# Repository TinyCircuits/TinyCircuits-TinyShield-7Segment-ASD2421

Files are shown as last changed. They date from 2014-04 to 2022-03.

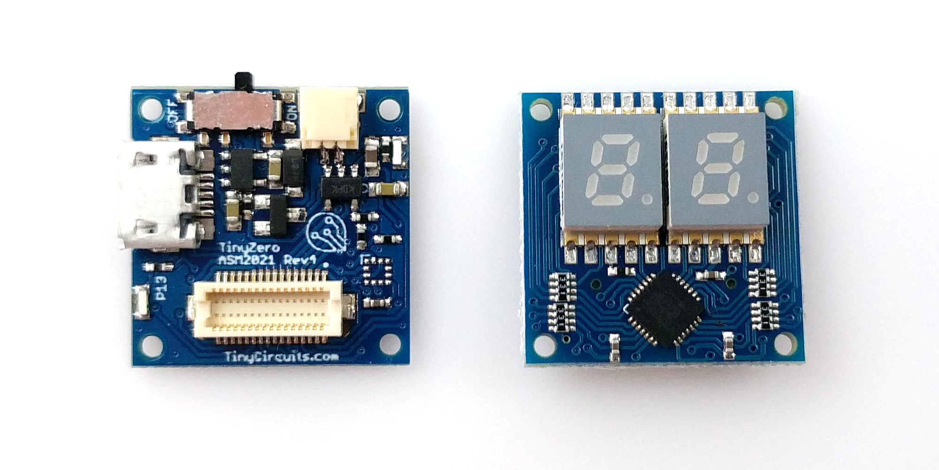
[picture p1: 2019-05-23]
images/ASD2421-R-N-Tutorial-Image-02.jpg

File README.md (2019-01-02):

# TinyCircuits TinyShield 7 Segment Display
# ASD2421 Rev2

The design files are located under design_files/ for the TinyCircuits ASD2421 Rev 2 PCB.  This is a Tiny shield board (Square Version, 20mm x 20mm) that has two seven segment displays (Red LEDs).  

Format is in Cadsoft Eagle format - Eagle version 6.2 was used for the original design.

For more infomation on this, check out the product page at TinyCircuits.com:  https://tinycircuits.com/collections/leds-displays/products/7-segment-display-tinyshield

# License:

Design by TinyCircuits.
All design files are released under the Creative Commons Attribution Share-Alike 3.0 License, see the following link for details: http://creativecommons.org/licenses/by-sa/3.0

All text above must be included in any redistribution or derived design

This project uses designs and concepts developed as part of the Arduino project and the LilyPad project.  The TinyCircuits design files themselves (schematics, PCB and libraries) are not directly derived from these works' design files and have been created new, however the concepts and basic architecture behind the TinyDuino and TinyLily products are derived and we thank the hard work of the organizations below for their contributions to open-source hardware:
  
Original Arduino Uno Design by Team Arduino

LilyPad Arduino Design by Leah Buechley and Sparkfun Electronics

Please support the open-source hardware community

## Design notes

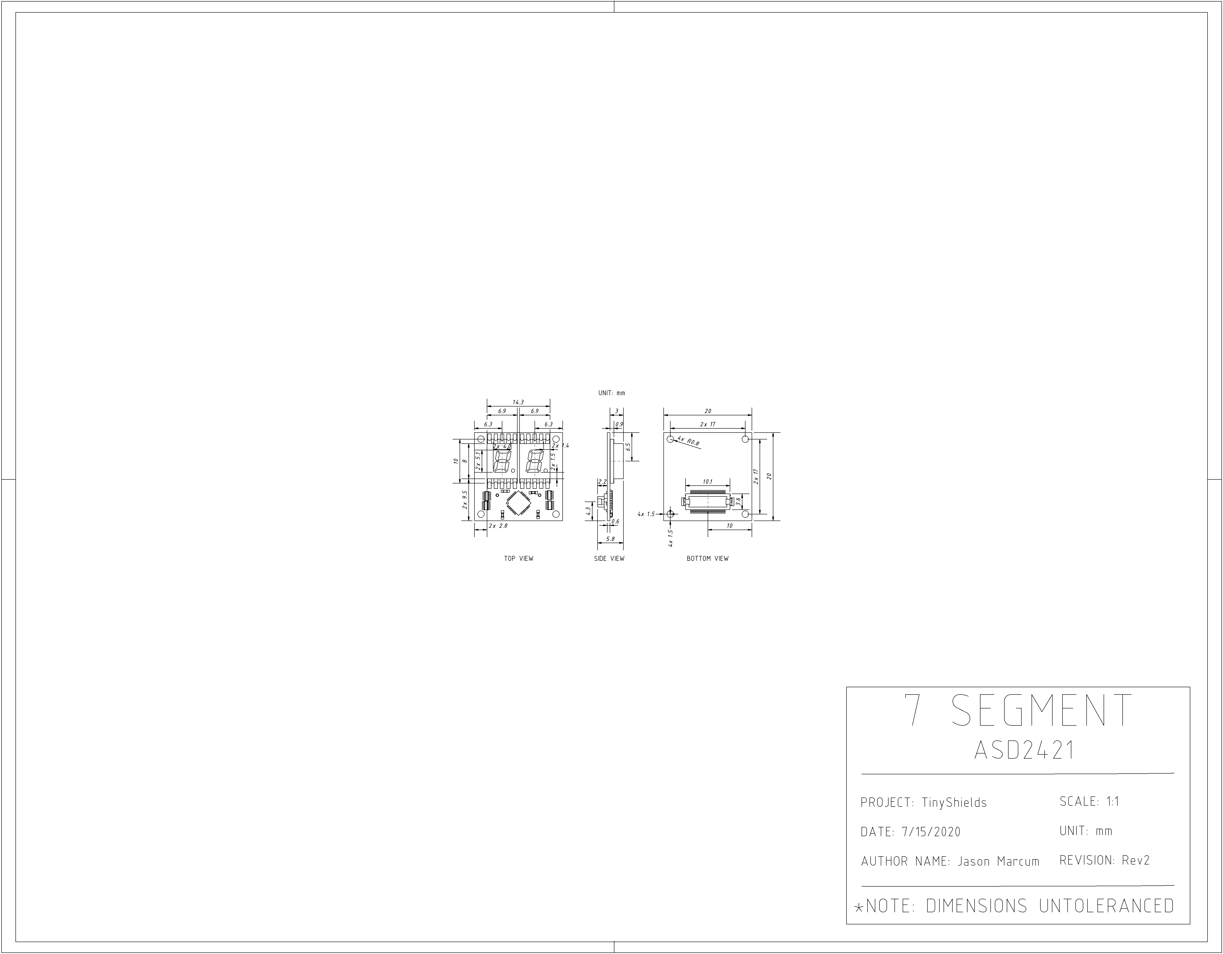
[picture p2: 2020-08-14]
cad/TinyShield_7SEGMENT_ASD2421_REV2-DETAILED_DRAWING-PNG.png

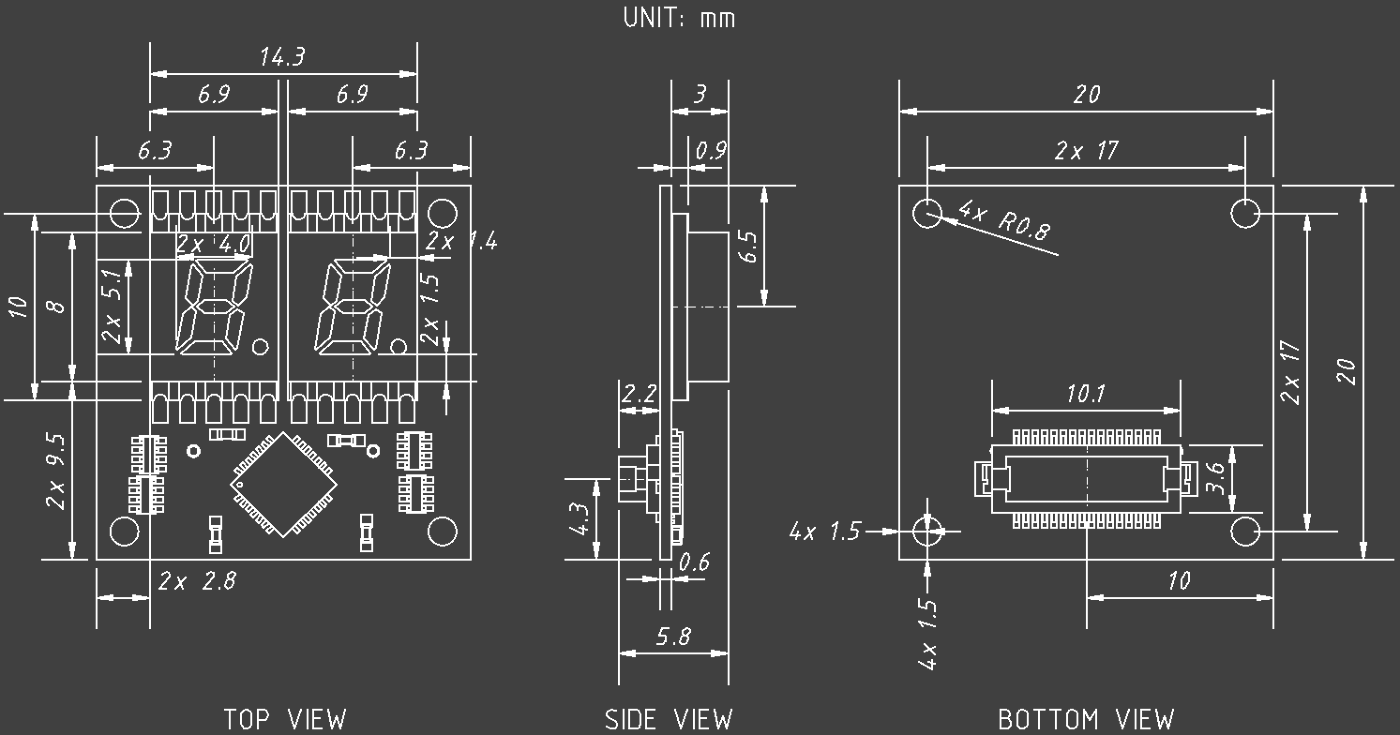
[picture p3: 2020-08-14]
cad/TinyShield_7SEGMENT_ASD2421_REV2-DETAILED_DRAWING_COMPACT-PNG.png

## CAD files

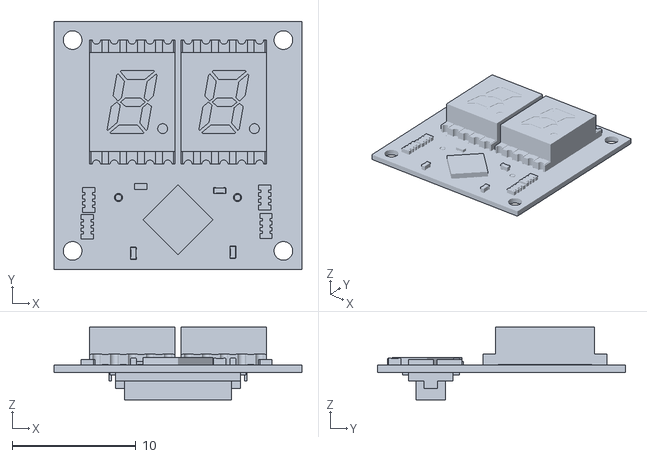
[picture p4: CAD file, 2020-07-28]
cad/TinyShield_7SEGMENT_ASD2421_REV2-STL.stl
20.0 x 20.0 x 5.85

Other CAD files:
cad/TinyShield_7SEGMENT_ASD2421_REV2-DETAILED_DRAWING-DXF.dxf

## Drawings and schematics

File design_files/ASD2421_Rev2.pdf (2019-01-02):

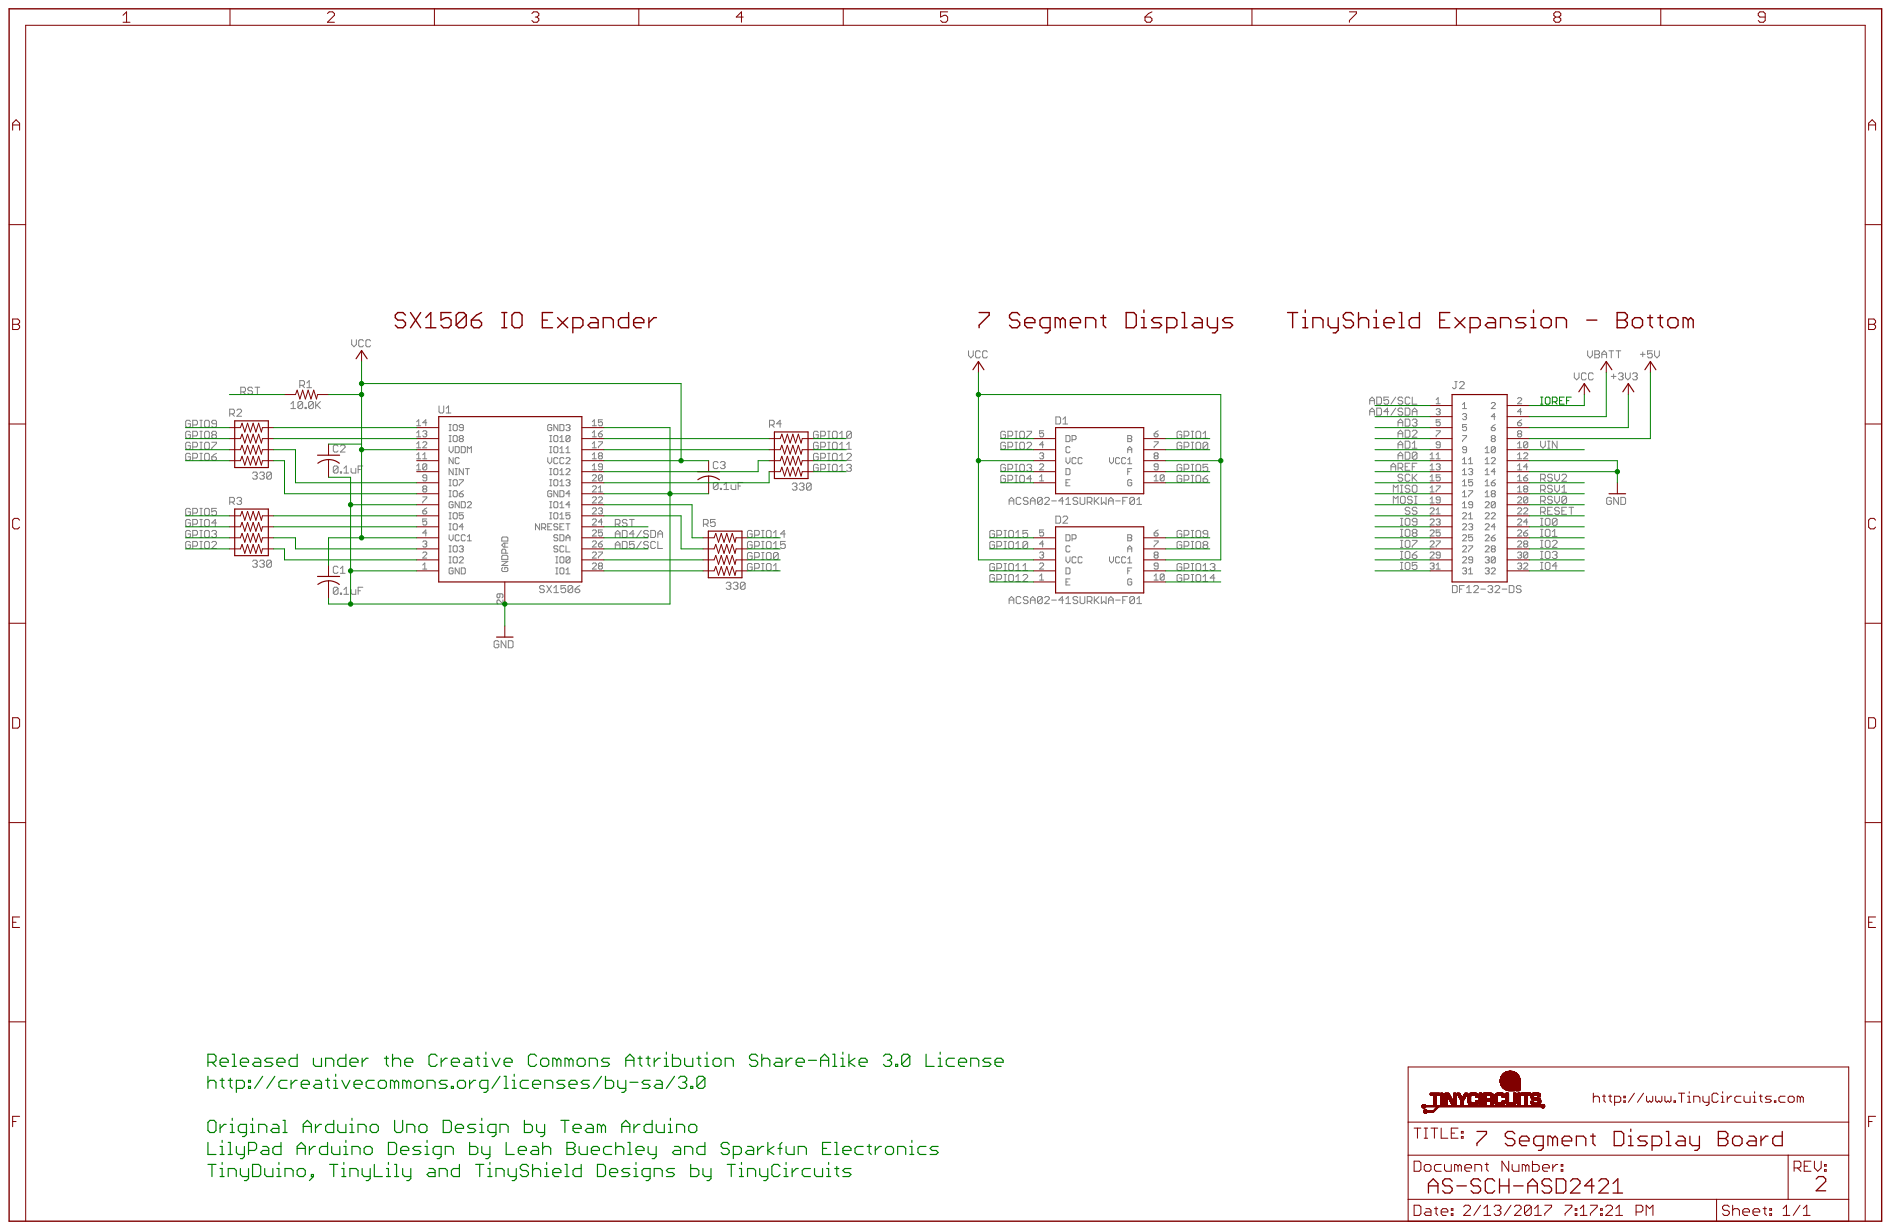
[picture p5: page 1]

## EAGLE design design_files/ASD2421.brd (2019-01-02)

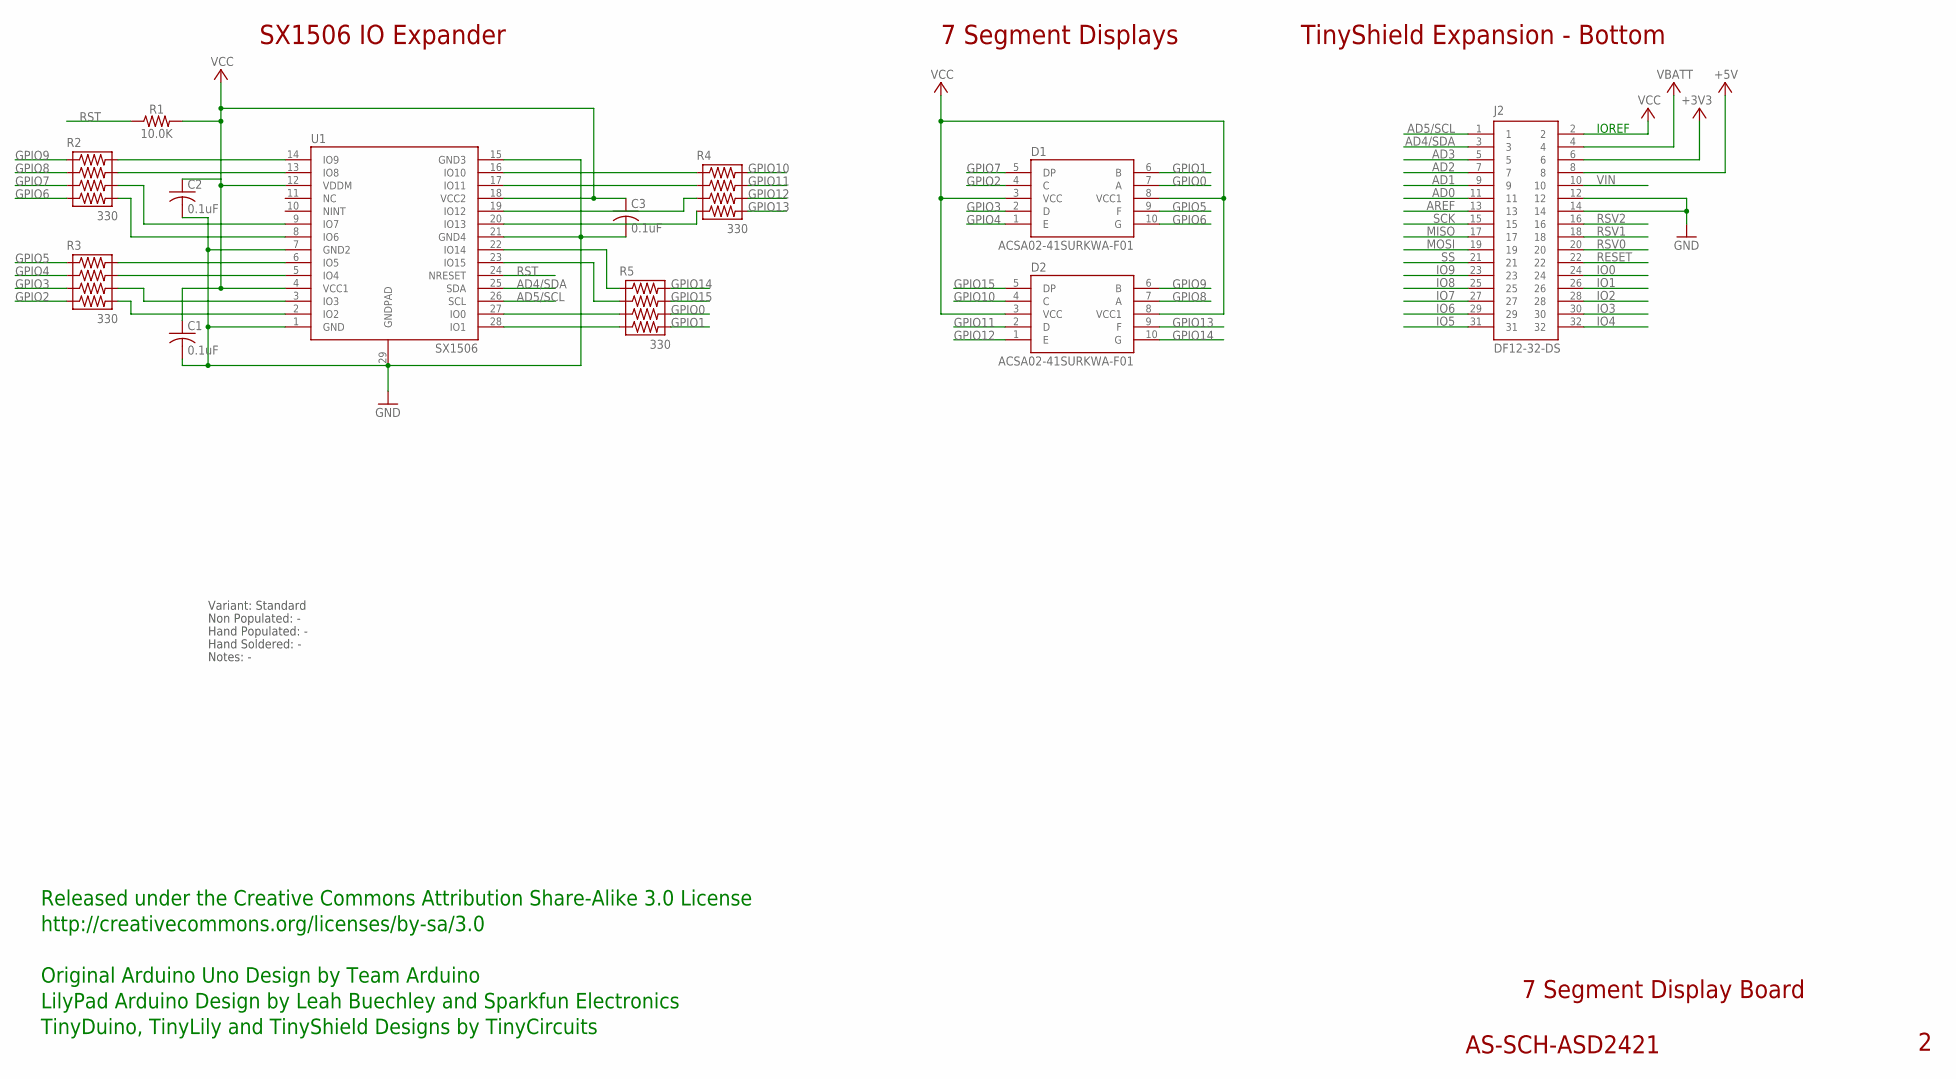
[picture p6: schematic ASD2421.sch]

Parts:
C1, C2, C3: 0.1uF; C0402
D1, D2: ACSA02-41SURKWA-F01; PARTNO AS-ITM-00133
J2: DF12-32-DS; PARTNO AS-ITM-00012
R1: 10.0K; 0402
R2, R3, R4, R5: 330; 0402RPACK
U1: SX1506; PARTNO AS-ITM-00134

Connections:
+3V3: J2.6
+5V: J2.8
AD0: J2.11
AD1: J2.9
AD2: J2.7
AD3: J2.5
AD4/SDA: J2.3, U1.25 (SDA)
AD5/SCL: J2.1, U1.26 (SCL)
AREF: J2.13
GND: C1.2, C2.2, C3.2, J2.12, J2.14, U1.1 (GND), U1.7 (GND2), U1.15 (GND3), U1.21 (GND4), U1.29 (GNDPAD)
GPIO0: D1.7 (A), R5.6
GPIO1: D1.6 (B), R5.8
GPIO2: D1.4 (C), R3.7
GPIO3: D1.2 (D), R3.5
GPIO4: D1.1 (E), R3.3
GPIO5: D1.9 (F), R3.1
GPIO6: D1.10 (G), R2.7
GPIO7: D1.5 (DP), R2.5
GPIO8: D2.7 (A), R2.3
GPIO9: D2.6 (B), R2.1
GPIO10: D2.4 (C), R4.2
GPIO11: D2.2 (D), R4.4
GPIO12: D2.1 (E), R4.6
GPIO13: D2.9 (F), R4.8
GPIO14: D2.10 (G), R5.2
GPIO15: D2.5 (DP), R5.4
IO0: J2.24
IO1: J2.26
IO2: J2.28
IO3: J2.30
IO4: J2.32
IO5: J2.31
IO6: J2.29
IO7: J2.27
IO8: J2.25
IO9: J2.23
MISO: J2.17
MOSI: J2.19
unnamed: R2.2, U1.14 (IO9)
unnamed: R2.4, U1.13 (IO8)
unnamed: R2.6, U1.9 (IO7)
unnamed: R2.8, U1.8 (IO6)
unnamed: R3.2, U1.6 (IO5)
unnamed: R3.4, U1.5 (IO4)
unnamed: R3.6, U1.3 (IO3)
unnamed: R3.8, U1.2 (IO2)
unnamed: R4.1, U1.16 (IO10)
unnamed: R4.3, U1.17 (IO11)
unnamed: R4.5, U1.19 (IO12)
unnamed: R4.7, U1.20 (IO13)
unnamed: R5.1, U1.22 (IO14)
unnamed: R5.3, U1.23 (IO15)
unnamed: R5.5, U1.27 (IO0)
unnamed: R5.7, U1.28 (IO1)
RESET: J2.22
RST: R1.1, U1.24 (NRESET)
RSV0: J2.20
RSV1: J2.18
RSV2: J2.16
SCK: J2.15
SS: J2.21
VBATT: J2.4
VCC: C1.1, C2.1, C3.1, D1.3 (VCC), D1.8 (VCC1), D2.3 (VCC), D2.8 (VCC1), J2.2, R1.2, U1.4 (VCC1), U1.12 (VDDM), U1.18 (VCC2)
VIN: J2.10

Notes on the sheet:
TinyShield Expansion - Bottom
7 Segment Display Board
AS-SCH-ASD2421
IOREF
Released under the Creative Commons Attribution Share-Alike 3.0 License
http://creativecommons.org/licenses/by-sa/3.0
LilyPad Arduino Design by Leah Buechley and Sparkfun Electronics
TinyDuino, TinyLily and TinyShield Designs by TinyCircuits
Original Arduino Uno Design by Team Arduino
SX1506 IO Expander
7 Segment Displays
Non Populated: -
Hand Populated: -
Hand Soldered: -
Notes: -
Variant: Standard

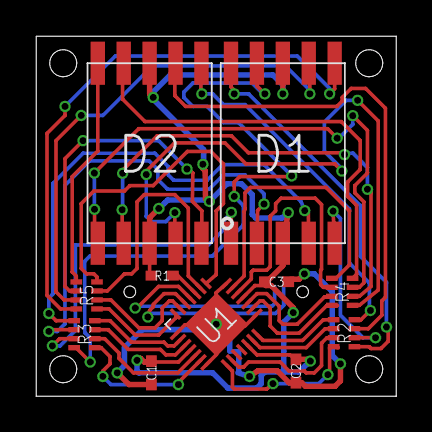
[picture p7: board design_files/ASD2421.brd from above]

Board: 2 copper layers, 20.0 x 20.0 mm, 13 parts (1 on the bottom side), 37 nets.

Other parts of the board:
U$1: DOCFIELD-TINYCIRCUITS-PCB

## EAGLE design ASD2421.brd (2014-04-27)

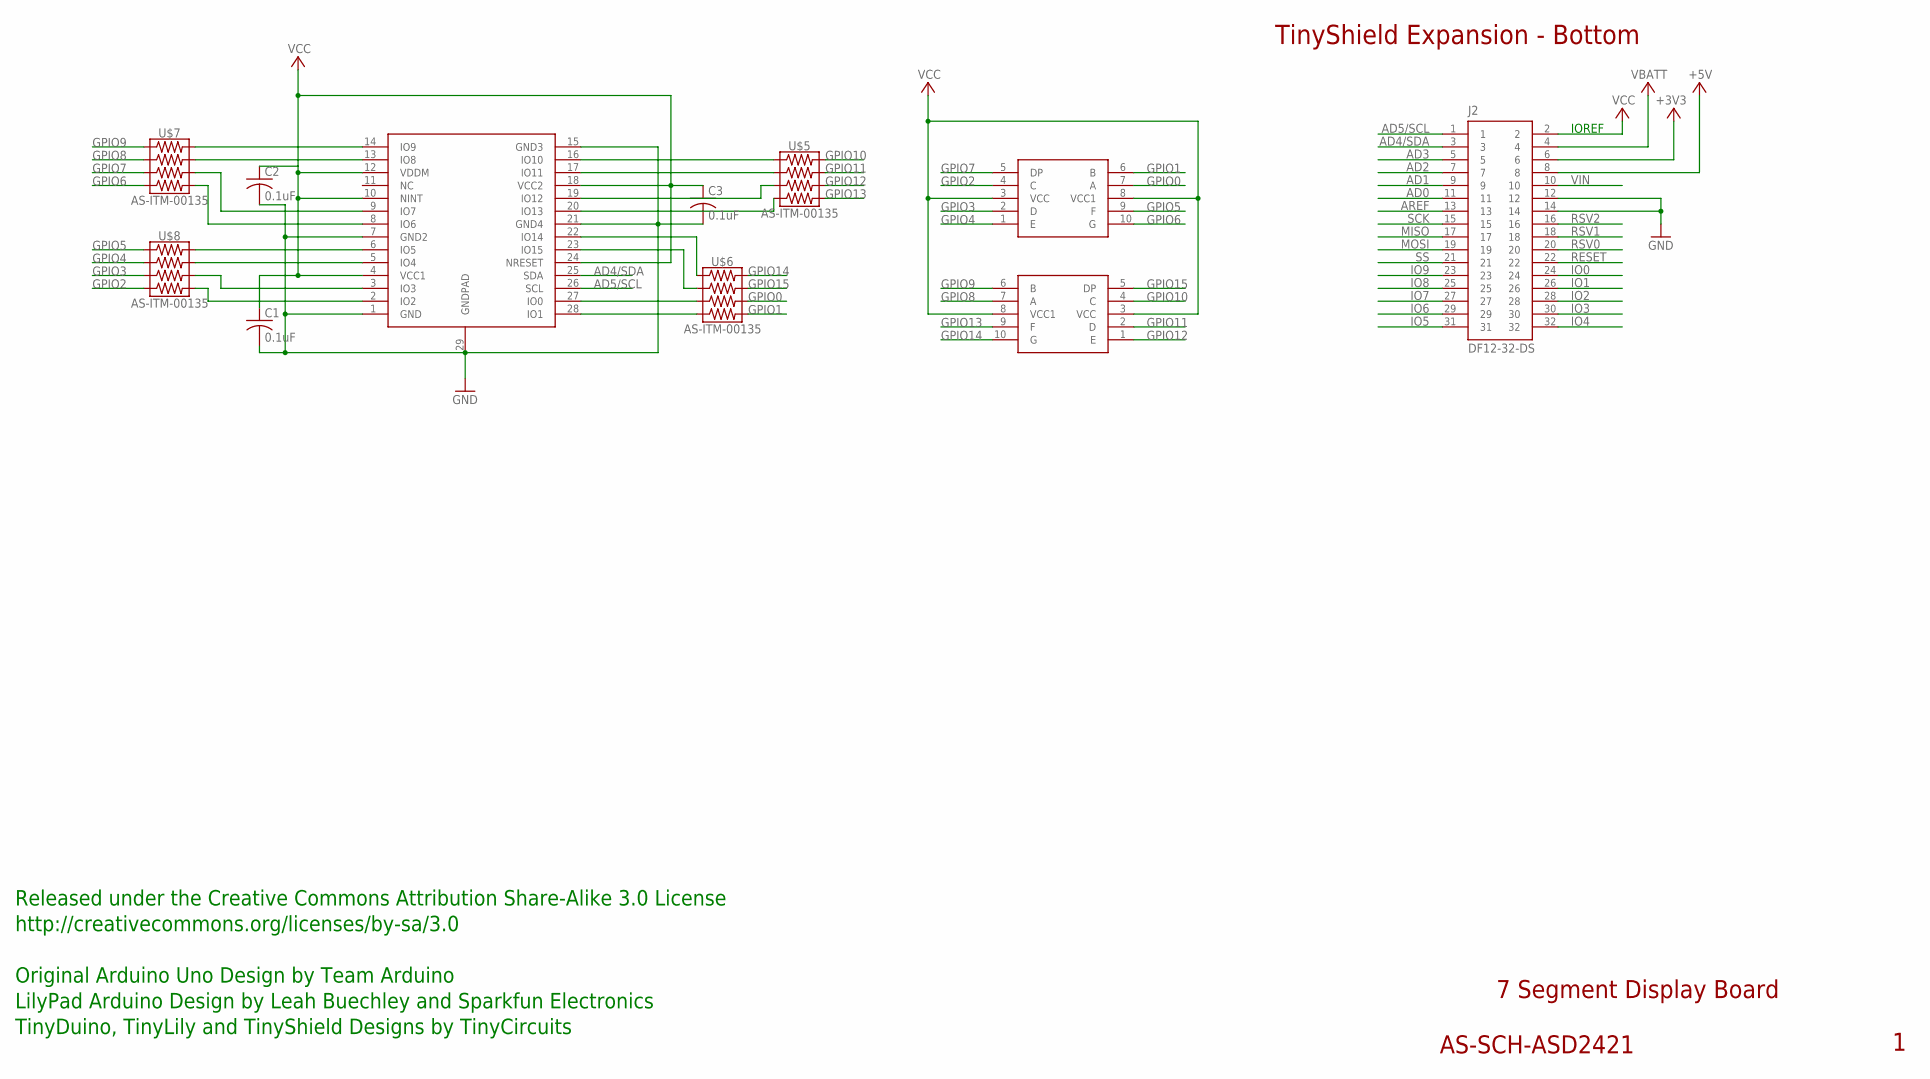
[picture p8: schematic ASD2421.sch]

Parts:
C1, C2, C3: 0.1uF; C0402
J2: DF12-32-DS; PARTNO AS-ITM-00012
U$2, U$3: AS-ITM-00133; ACSA02-41SURKWA-F01
U$4: AS-ITM-00134; SX1506
U$5, U$6, U$7, U$8: AS-ITM-00135; 0402RPACK

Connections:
+3V3: J2.6
+5V: J2.8
AD0: J2.11
AD1: J2.9
AD2: J2.7
AD3: J2.5
AD4/SDA: J2.3, U$4.25 (SDA)
AD5/SCL: J2.1, U$4.26 (SCL)
AREF: J2.13
GND: C1.2, C2.2, C3.2, J2.12, J2.14, U$4.1 (GND), U$4.7 (GND2), U$4.15 (GND3), U$4.21 (GND4), U$4.29 (GNDPAD)
GPIO0: U$2.7 (A), U$6.6
GPIO1: U$2.6 (B), U$6.8
GPIO2: U$2.4 (C), U$8.7
GPIO3: U$2.2 (D), U$8.5
GPIO4: U$2.1 (E), U$8.3
GPIO5: U$2.9 (F), U$8.1
GPIO6: U$2.10 (G), U$7.7
GPIO7: U$2.5 (DP), U$7.5
GPIO8: U$3.7 (A), U$7.3
GPIO9: U$3.6 (B), U$7.1
GPIO10: U$3.4 (C), U$5.2
GPIO11: U$3.2 (D), U$5.4
GPIO12: U$3.1 (E), U$5.6
GPIO13: U$3.9 (F), U$5.8
GPIO14: U$3.10 (G), U$6.2
GPIO15: U$3.5 (DP), U$6.4
IO0: J2.24
IO1: J2.26
IO2: J2.28
IO3: J2.30
IO4: J2.32
IO5: J2.31
IO6: J2.29
IO7: J2.27
IO8: J2.25
IO9: J2.23
MISO: J2.17
MOSI: J2.19
unnamed: U$4.14 (IO9), U$7.2
unnamed: U$4.13 (IO8), U$7.4
unnamed: U$4.9 (IO7), U$7.6
unnamed: U$4.8 (IO6), U$7.8
unnamed: U$4.6 (IO5), U$8.2
unnamed: U$4.5 (IO4), U$8.4
unnamed: U$4.3 (IO3), U$8.6
unnamed: U$4.2 (IO2), U$8.8
unnamed: U$4.16 (IO10), U$5.1
unnamed: U$4.17 (IO11), U$5.3
unnamed: U$4.19 (IO12), U$5.5
unnamed: U$4.20 (IO13), U$5.7
unnamed: U$4.22 (IO14), U$6.1
unnamed: U$4.23 (IO15), U$6.3
unnamed: U$4.27 (IO0), U$6.5
unnamed: U$4.28 (IO1), U$6.7
RESET: J2.22
RSV0: J2.20
RSV1: J2.18
RSV2: J2.16
SCK: J2.15
SS: J2.21
VBATT: J2.4
VCC: C1.1, C2.1, C3.1, J2.2, U$2.3 (VCC), U$2.8 (VCC1), U$3.3 (VCC), U$3.8 (VCC1), U$4.4 (VCC1), U$4.10 (NINT), U$4.12 (VDDM), U$4.18 (VCC2), U$4.24 (NRESET)
VIN: J2.10

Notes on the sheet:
TinyShield Expansion - Bottom
7 Segment Display Board
AS-SCH-ASD2421
IOREF
Released under the Creative Commons Attribution Share-Alike 3.0 License
http://creativecommons.org/licenses/by-sa/3.0
LilyPad Arduino Design by Leah Buechley and Sparkfun Electronics
TinyDuino, TinyLily and TinyShield Designs by TinyCircuits
Original Arduino Uno Design by Team Arduino

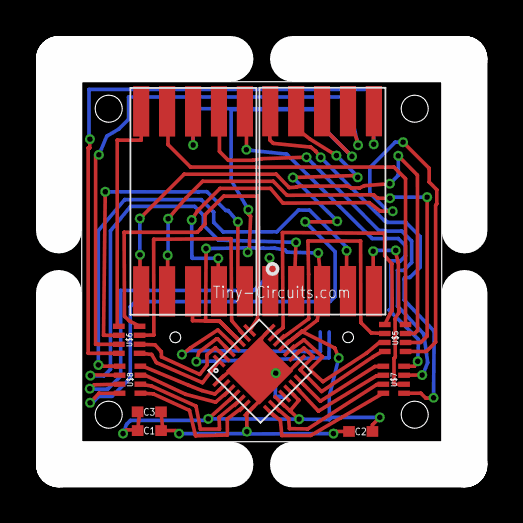
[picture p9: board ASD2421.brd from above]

Board: 2 copper layers, 20.0 x 20.0 mm, 12 parts (1 on the bottom side), 36 nets.

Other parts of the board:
U$1: DOCFIELD-TINYCIRCUITS-PCB

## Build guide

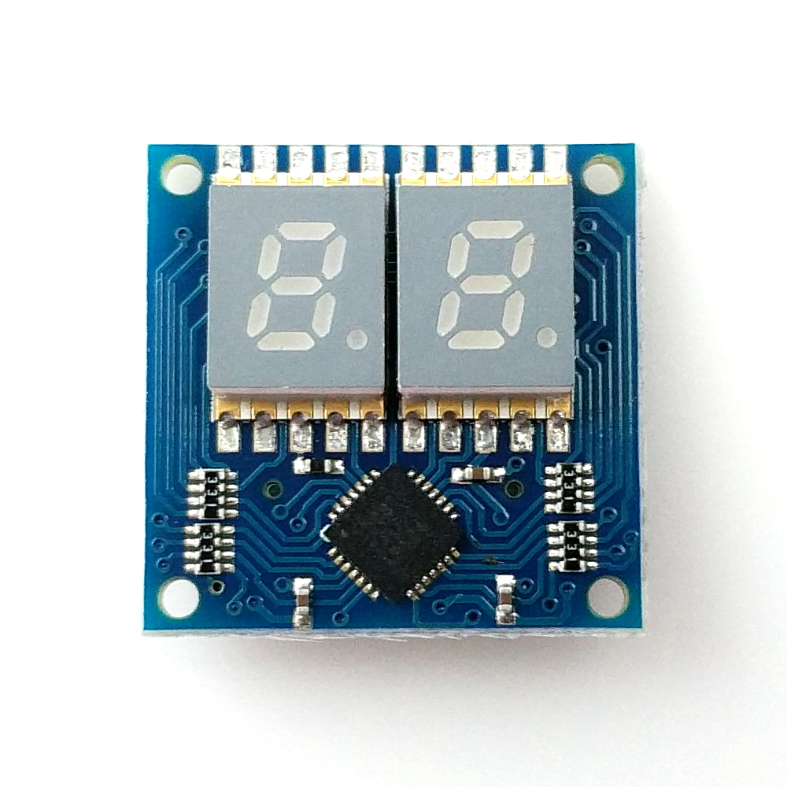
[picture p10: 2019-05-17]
images/ASD2421-R-N-Tutorial-Image-01.jpg

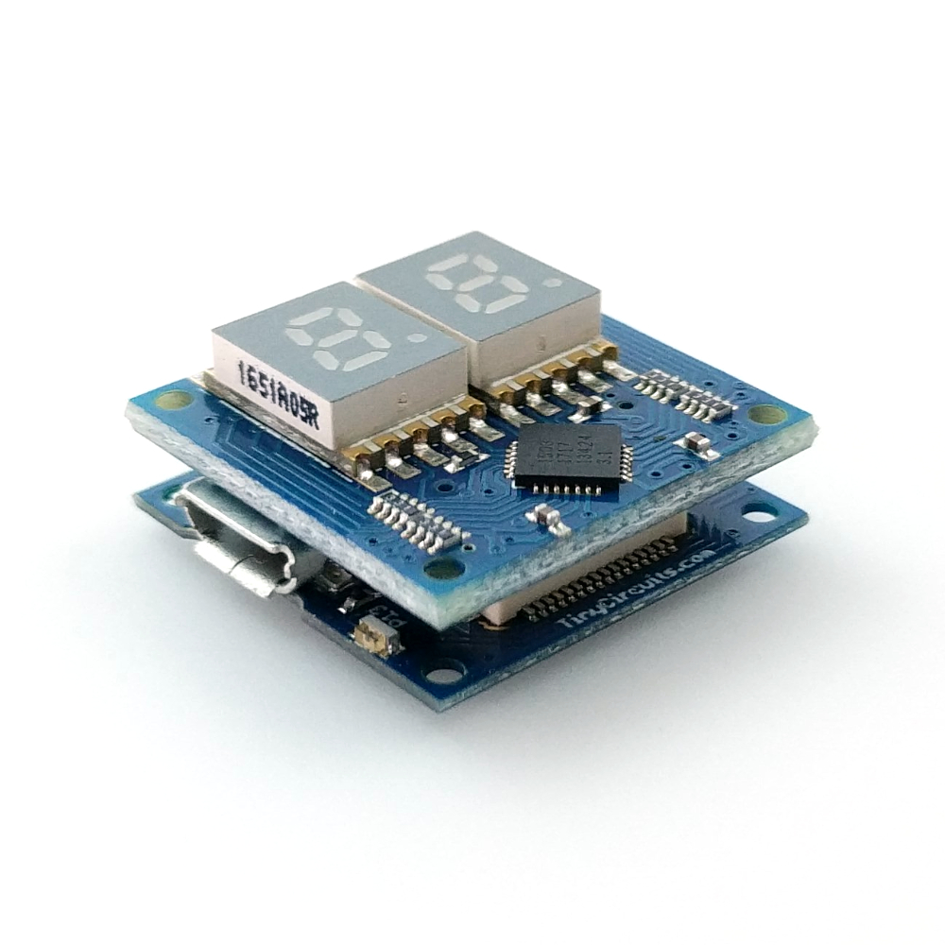
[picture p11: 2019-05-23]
images/ASD2421-R-N-Tutorial-Image-03.jpg

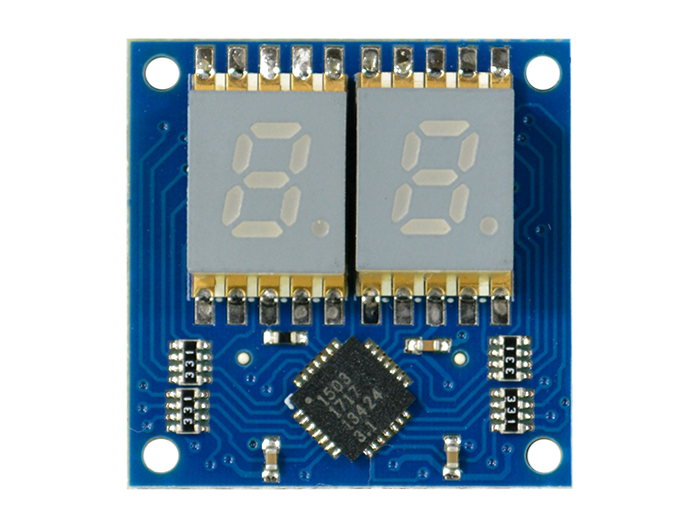
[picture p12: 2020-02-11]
images/ASD2421-R-N-Tutorial-Image-01.png

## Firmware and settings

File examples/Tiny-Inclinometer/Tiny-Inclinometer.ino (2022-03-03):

/*
TinyDuino Accelerometer & 7Segment display Demo

This example code is in the public domain.

January 12, 2015 by Tony Batey

https://tiny-circuits.com/

*/

#include "Wire.h"
#include "BMA250.h"
#include "Tiny7Seg.h"

BMA250 accel;
Tiny7Seg seg;

void setup()
{
  Wire.begin();
  seg.init();                                              //This initializes the I/O expander on the 7 segment display
  accel.begin(BMA250_range_2g, BMA250_update_time_64ms);    //This sets up the BMA250 accelerometer
}

void loop()
{
  accel.read();                                          //This function gets new data from the accelerometer
  float angle = atan2(accel.Y, accel.X) * 180.0/PI;      //math to calculate the angle from the sensor readings
  angle = constrain(angle-90.0,-90.0,90.0);              //We only want angles from -90 to 90
  seg.printInt(abs(angle));                              //Then, we'll just display the absolute value
  delay(100);                                            //We'll make sure we're over the 64ms update time set on the BMA250
}

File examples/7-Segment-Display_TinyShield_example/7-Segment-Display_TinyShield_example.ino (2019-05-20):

/*
  TinyCircuits 7 Segment Display TinyShield Example Sketch
  
  This sketch demonstrates the functionality of the display by
  counting down from 5, flashing "00" three times, then toggles
  the decimal segments indefinitely.

  Written 
  By 
  Modified 07 January 2019
  By Hunter Hykes

  https://TinyCircuits.com
*/

#include <Wire.h>
#include "Tiny7Seg.h"

Tiny7Seg seg;

void setup()
{
  Wire.begin();
  seg.init();
  for(int i=5; i>0; i--){
    seg.printInt(i);
    delay(500);
  };
  for(int i=0; i<5; i++){
    seg.printInt(0);
    delay(100);
    seg.off();
    delay(100);
  };
}

void loop()
{
  seg.setDecPoints(1,0);
  delay(50);
  seg.setDecPoints(0,1);
  delay(50);
}

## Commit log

2019-01-02 Update Rev and Format
    [ASD2421.brd, ASD2421.sch]
2020-07-28 Add CAD data
    [TinyShield_7SEGMENT_ASD2421_REV2-DETAILED_DRAWING-DXF.dxf, TinyShield_7SEGMENT_ASD2421_REV2-STL.stl]
2020-08-14 Update CAD drawing
    [TinyShield_7SEGMENT_ASD2421_REV2-DETAILED_DRAWING-DXF.dxf]
